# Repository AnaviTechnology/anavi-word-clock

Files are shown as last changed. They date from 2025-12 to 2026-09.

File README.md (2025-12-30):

# ANAVI Word Clock

Open source 8x8 NeoPixel word clock.

# Case

The case is designed using the free and open-source tool OpenSCAD and requires a custom stencil font.

## Installing the Stencil Font on Ubuntu

Follow the steps below to install the Arial stencil font on an Ubuntu Linux distribution:

*  Copy the font file:

```
sudo mkdir /usr/share/fonts/anavi
sudo cp Arial-BoldStencila.ttf /usr/share/fonts/anavi
sudo chmod -R --reference=/usr/share/fonts/opentype /usr/share/fonts/anavi
```

NOTE: Root privileges are required to install fonts system-wide.

* Update the font cache:

```
sudo fc-cache -fv
```

* Verify the installation:

```
fc-list | grep -i arial
```

The font should appear in the output list. The font name reported by fc-list must be used exactly in the OpenSCAD text() function.

* Launch OpenSCAD

Restart OpenSCAD if it was already running so it can detect the newly installed font.

# License

The project is released under the [Creative Commons Attribution-ShareAlike 4.0 International (CC BY-SA 4.0)](https://creativecommons.org/licenses/by-sa/4.0/).

Note: This is a human-readable summary of (and not a substitute for) the [license](https://creativecommons.org/licenses/by-sa/4.0/legalcode).

You are free to:

Share — copy and redistribute the material in any medium or format Adapt — remix, transform, and build upon the material for any purpose, even commercially. The licensor cannot revoke these freedoms as long as you follow the license terms. Under the following terms:

Attribution — You must give appropriate credit, provide a link to the license, and indicate if changes were made. You may do so in any reasonable manner, but not in any way that suggests the licensor endorses you or your use. ShareAlike — If you remix, transform, or build upon the material, you must distribute your contributions under the same license as the original. No additional restrictions — You may not apply legal terms or technological measures that legally restrict others from doing anything the license permits. Notices:

You do not have to comply with the license for elements of the material in the public domain or where your use is permitted by an applicable exception or limitation. No warranties are given. The license may not give you all of the permissions necessary for your intended use. For example, other rights such as publicity, privacy, or moral rights may limit how you use the material.

You will have to provide a link to the original creator of the project http://www.anavi.technology on any documentation or website.

Credit can be attributed through a link to the creator website: http://www.anavi.technology

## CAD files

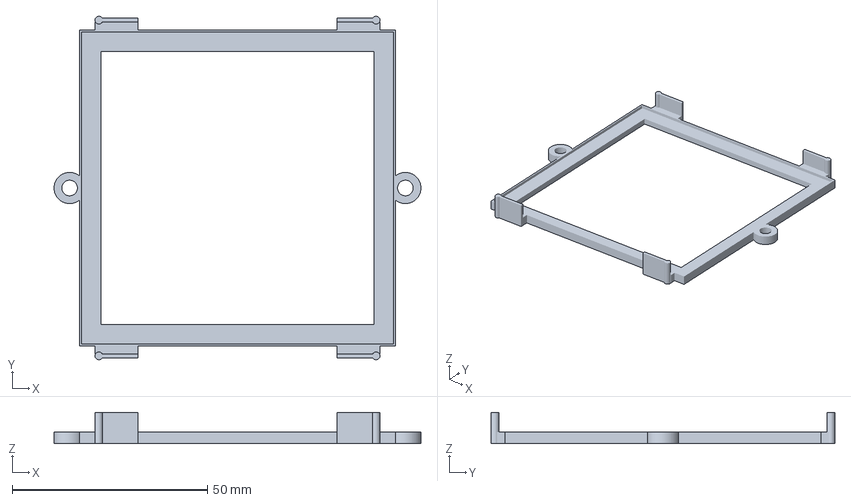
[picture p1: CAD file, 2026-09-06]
case/anavi-word-clock-panel.3mf
94.0 x 88.0 x 8.00 mm

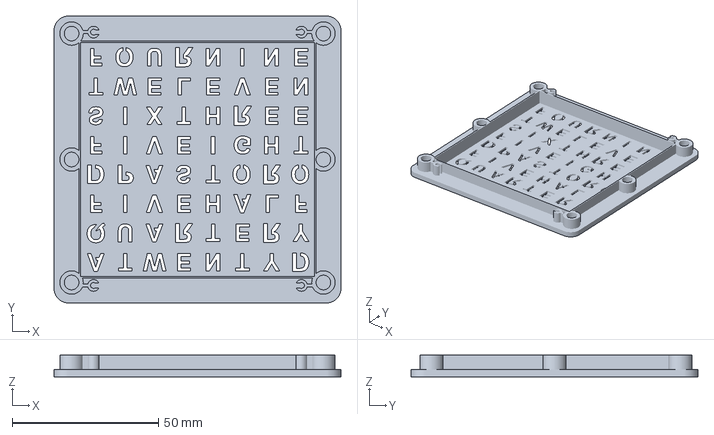
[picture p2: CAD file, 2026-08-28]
case/anavi-word-clock-top.3mf
98.0 x 98.0 x 7.50 mm

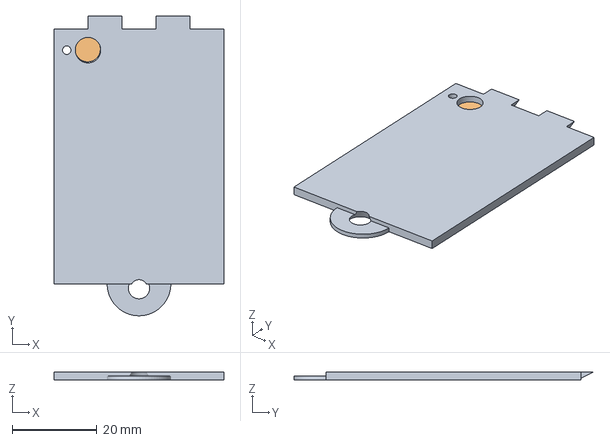
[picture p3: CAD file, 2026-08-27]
case/anavi-word-clock-cover.3mf
40.0 x 70.5 x 2.00 mm
anavi-word-clock-cover.stl
anavi-word-clock-cover-led.stl

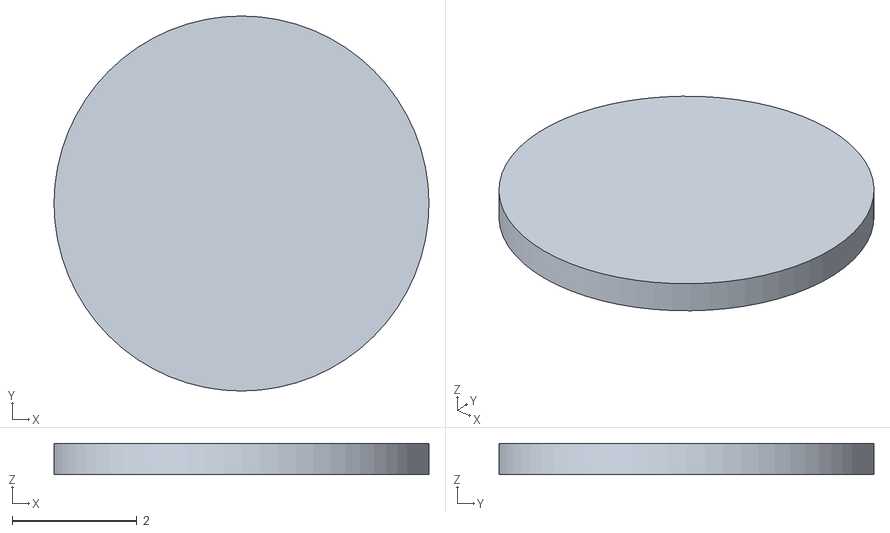
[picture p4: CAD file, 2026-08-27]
case/anavi-word-clock-cover-led.stl
6.00 x 6.00 x 0.5

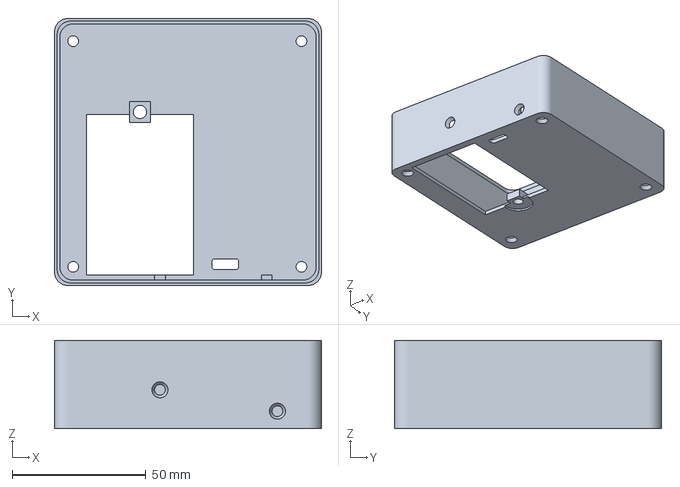
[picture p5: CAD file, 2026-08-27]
case/anavi-word-clock-back.3mf
100.0 x 100.0 x 33.0 mm

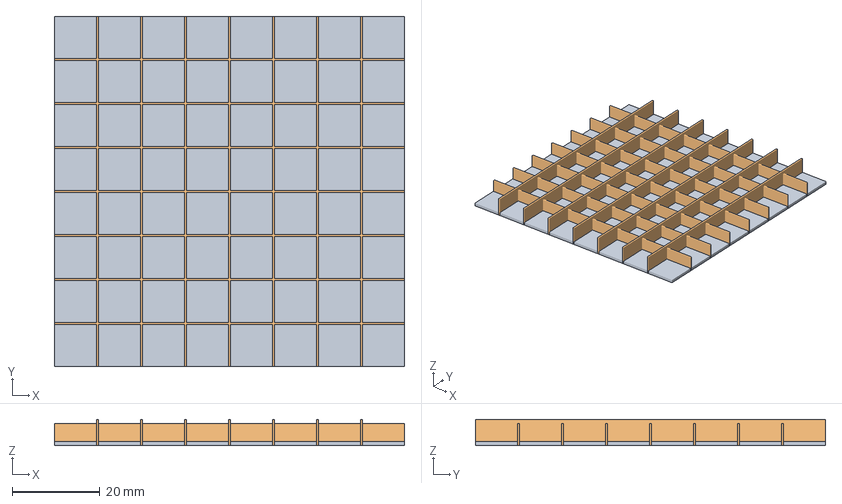
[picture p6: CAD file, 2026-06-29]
case/anavi-word-clock-grid-with-diffuser.3mf
80.0 x 80.0 x 6.00 mm
anavi-word-clock-diffuser.stl
anavi-word-clock-grid.stl

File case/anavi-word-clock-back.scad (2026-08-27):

// ========================
// Parameters
// ========================
// Corner radius
corner_r = 5;

// Wall thickness
wall_thickness = 2;
// smooth corners
$fn = 64;


// Case
case_width = 100;
case_lenght = 100;
case_height = 33;

// Outer cylinder
outer_r = 3;
outer_h = 4;

// Inner hole
hole_r = 3;
hole_h = 2;

// USB-C connector
usbc_l = 10;
usbc_h = 4;

// LED
led_r = 5;

// increase for smoother cone ($fn)
segments = 64;

// ========================
// Case Top Module
// ========================
module case_top() {

    // Translate so inner PCB pocket starts at (0,0)
    translate([corner_r, corner_r, 0]) {
        difference() {
            // Outer shell (walls included)
            linear_extrude(height = case_height)
                rounded_rect(case_width,
                             case_lenght,
                             corner_r);

            // Main hollow interior
            translate([wall_thickness, wall_thickness, wall_thickness])
                linear_extrude(height = case_height-3)
                    rounded_rect(case_width-2*wall_thickness, case_lenght-2*wall_thickness, corner_r);
            
            // Top hollow interior
            translate([wall_thickness/2, wall_thickness/2, case_height-3])
                linear_extrude(height = 3)
                    rounded_rect(case_width-wall_thickness, case_lenght-wall_thickness, corner_r);

            // Mounting hole 1 (top left)
            translate([2, case_lenght-4.5-hole_r*3, 0])
                // Cone
                cylinder(wall_thickness, hole_r, hole_h, center = false, $fn = segments);
            
            // Mounting hole 2 (top right)
            translate([case_width-4.5-hole_r*3+1, case_lenght-4.5-hole_r*3, 0])
                // Cone
                cylinder(wall_thickness, hole_r, hole_h, center = false, $fn = segments);

            // Mounting hole 2 (top right)
            translate([case_width-4.5-hole_r*3+1, hole_h, 0])
                // Cone
                cylinder(wall_thickness, hole_r, hole_h, center = false, $fn = segments);
            
            // Mounting hole 4 (bottom left)
            translate([2, 2, 0])
                // Cone
                cylinder(wall_thickness, hole_r, hole_h, center = false, $fn = segments);
        }
    }
    
    // Covel bottom holders
    translate([12+8-2, 2, wall_thickness])
        cube([12, 2, 2]);
    translate([12+24-2, 2, wall_thickness])
        cube([12, 2, 2]);

    // PCB stand
    middle = (case_width-usbc_l)/2+4;
    translate([middle-9.5-2, 2, wall_thickness])
        cube([4, 2, 10]);
    translate([middle+34.50-6, 2, wall_thickness])
        cube([4, 2, 23]);
}

// ========================
// Rounded rectangle module
// ========================
module rounded_rect(x, y, radius) {
    minkowski() {
        square([x - 2*radius, y - 2*radius], center = false);
        circle(r = radius, $fn = $fn);
    }
}

// ========================
// Mounting hole
// ========================
module mounting_hole() {
    difference() {
        // Outer cylinder
        cylinder(h = outer_h, r = outer_r, $fn = 64);
        
        // Inner hole
        translate([0, 0, outer_h-hole_h])  // hole starts at base
            cylinder(h = hole_h, r = hole_r, $fn = 64);
    }
}

module usbc() {
    linear_extrude(height = wall_thickness)
        rounded_rect(usbc_l,usbc_h,1);
}

module ramp_screw() {
    rotate([90, 0, 270])
    linear_extrude(height = 8)
        polygon([
            [0, 0],
            [4, 0],
            [4, 1]
        ]);
}

module ramp() {
    rotate([270, 0, 90])
    linear_extrude(height = 8)
        polygon([
            [0, 0],
            [3, 0],
            [3, 3]
        ]);
}

// ========================
// Top case
// ========================

difference() {
    union() {
        difference() {
            // Main part of the case
            case_top();
            // USB-C connector
            translate([(case_width-usbc_l)/2+15, 7, 0])
               usbc();
            // PCB mounting holes
            middle = (case_width-usbc_l)/2+4;
            translate([middle-9.5, 2, wall_thickness+2.5+2+8])
                rotate([90, 0, 0])
                    cylinder(h = 2, r1 = 2, r2 = 3, center = false);

            translate([middle+34.5, 2, wall_thickness+2.5+2])
                rotate([90, 0, 0])
                    cylinder(h = 2, r1 = 2, r2 = 3, center = false);
            
            // Cover for the RTC module
            translate([12, 4, 0])
                cube([40, 60, 2]);
            translate([12+40/2,65,0])
                cylinder(h = 1, d = 15, $fn = segments);
            
            translate([12+16, 1, 3])
                ramp();
            translate([12+32, 1, 3])
                ramp();
        }
        
        // Holder for the cover's nut
        translate([8+40/2,61,1])
            cube([8, 8, 4]);
    }
    
    // Cover's mounting hole
    translate([12+40/2,65,1])
        cylinder(4, 2.5, 2.5, center = false, $fn = segments);

}

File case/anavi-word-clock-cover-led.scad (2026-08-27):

// increase for smoother cone ($fn)
segments = 64;

cylinder(0.5, 3, 3, center = false, $fn = segments);

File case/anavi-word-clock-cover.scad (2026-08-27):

// increase for smoother cone ($fn)
segments = 64;

// Inner hole
hole_r = 3;
hole_h = 2;

module ramp() {
    rotate([90, 0, 90])
    linear_extrude(height = 8)
        polygon([
            [0, 0],
            [3, 0],
            [3, 1.5]
        ]);
}

difference() {
    union() {
        cube([40, 60, 2]);
        translate([40/2,60,1])
            cylinder(h = 1, d = 15, $fn = segments);
        
        translate([8,-3,0])
            ramp();
        
        translate([24,-3,0])
            ramp();
    }

    // Opening for the screw
    translate([40/2,61,0])
        cylinder(2, hole_h, hole_r, center = false, $fn = segments);

    // Opening for the reset button
    translate([3,5,0])
        cylinder(2, 1, 1, center = false, $fn = segments);

    // LED
    translate([8,5,0])
        cylinder(2, 3, 3, center = false, $fn = segments);
}

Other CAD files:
case/anavi-word-clock-grid.scad
case/anavi-word-clock-back.stl
case/anavi-word-clock-cover.stl
case/anavi-word-clock-panel.scad
case/anavi-word-clock-panel.stl
case/anavi-word-clock-top.scad

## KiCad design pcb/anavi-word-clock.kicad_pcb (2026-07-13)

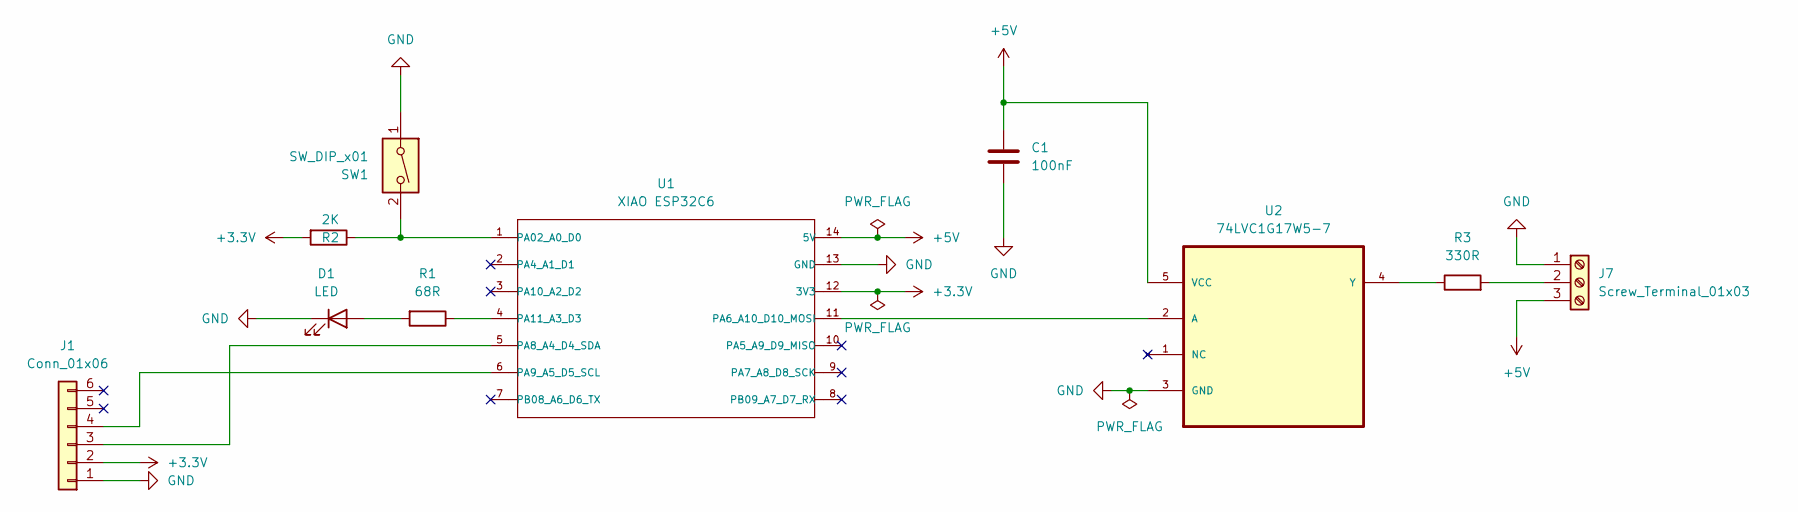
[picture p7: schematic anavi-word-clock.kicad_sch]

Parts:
C1: 100nF
D1: LED; LED_1206_3216Metric
J1: Conn_01x06; PinSocket_1x06_P2.54mm_Horizontal
J7: Screw_Terminal_01x03; TerminalBlock_Phoenix_MKDS-1,5-3_1x03_P5.00mm_Horizontal
R1: 68R; R_0603_1608Metric_Pad0.98x0.95mm_HandSolder
R2: 2K; R_0603_1608Metric_Pad0.98x0.95mm_HandSolder
R3: 330R; R_0603_1608Metric_Pad0.98x0.95mm_HandSolder
SW1: SW_DIP_x01; SW_TL1105SF160Q_EWI
U1: XIAO ESP32C6; XIAO-ESP32-C6-SMD
U2: 74LVC1G17W5-7; SOT95P280X145-5N; MPN 74LVC1G17W5-7

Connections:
+3.3V: J1.2, R2.2, U1.12 (3V3)
+5V: C1.1, J7.3, U1.14 (5V), U2.5 (VCC)
GND: C1.2, D1.1 (K), J1.1, J7.1, SW1.1, U1.13 (GND), U2.3 (GND)
unnamed: D1.2 (A), R1.2
unnamed: J1.3, U1.5 (PA8_A4_D4_SDA)
unnamed: J1.4, U1.6 (PA9_A5_D5_SCL)
unnamed: J7.2, R3.2
unnamed: R2.1, SW1.2, U1.1 (PA02_A0_D0)
unnamed: U1.11 (PA6_A10_D10_MOSI), U2.2 (A)
unnamed: R1.1, U1.4 (PA11_A3_D3)
unnamed: R3.1, U2.4 (Y)

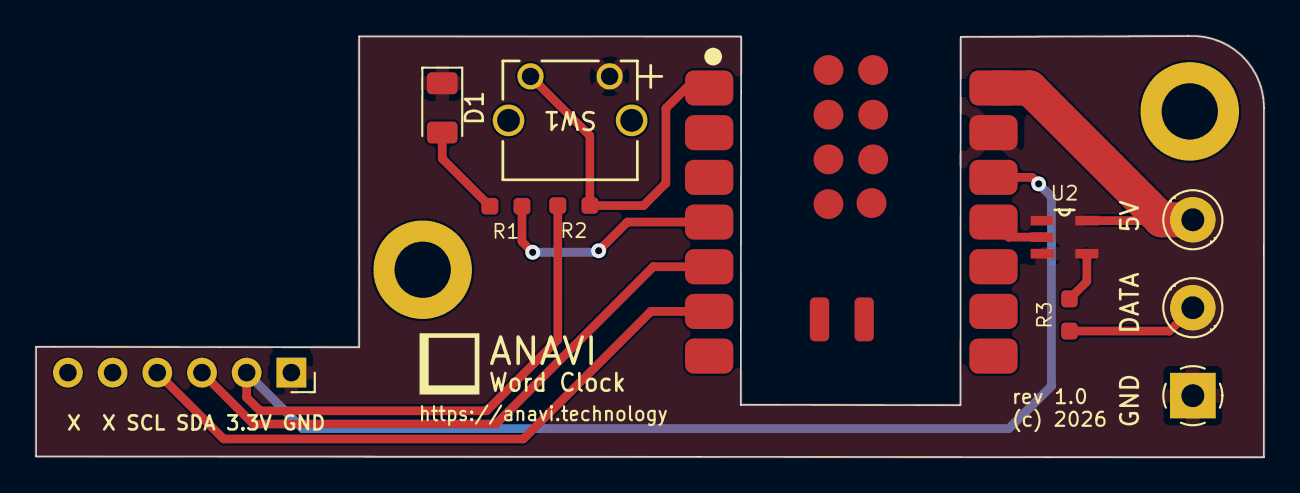
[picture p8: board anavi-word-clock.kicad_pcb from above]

Board: 2 copper layers, 69.8 x 23.9 mm, 9 parts (0 on the bottom side), 11 nets.

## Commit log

2025-12-29 case: Add anavi-word-clock-top.scad
    OpenSCAD design file for the top part with letters.
    [anavi-word-clock-top.scad]
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2025-12-30 case: Use stencil font
    Modify the top of the case to use the appropriate stencil font.
    [anavi-word-clock-top.scad]
2025-12-30 case/anavi-word-clock-top.scad: Add grid
    Add 8x8 grid with a cell for each NeoPixel.
    [anavi-word-clock-top.scad]
2025-12-30 case/anavi-word-clock-top.scad: Reduce size
    Reduce size from 100mm to 98mm. The top part is 2 mm shorter than
    the bottom, aka 1 mm on each side. So the whole case will be 10cm.
    [anavi-word-clock-top.scad]
2025-12-30 case: Add anavi-word-clock-back.scad
    Add OpenSCAD design for the back cover of the clock.
    [anavi-word-clock-back.scad]
2025-12-30 case/anavi-word-clock-top.scad: Grid height
    Reduce grid height to 4mm and adjust the position.
    [anavi-word-clock-top.scad]
2025-12-31 case/anavi-word-clock-diffuser.scad: Add
    Add a small plate that should act as a light diffuser.
    [anavi-word-clock-diffuser.scad]
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2026-01-01 case/anavi-word-clock-grid.scad: Add
    Add a 3D model of a grid between the NeoPixel panel (in its cover)
    and the diffuser.
    [anavi-word-clock-grid.scad]
2026-01-01 case/anavi-word-clock-top.scad: Mounting holes
    Add mounting holes in the middle to hold the NeoPixel panel.
    [anavi-word-clock-top.scad]
2026-01-03 case/anavi-word-clock-panel.scad: Add hooks
    Add four hooks to firmly attach the panel with NeoPixels to the
    front part of the clock.
    [anavi-word-clock-panel.scad]
2026-01-03 case/anavi-word-clock-top.scad: Add hooks
    Increase grid height to 5mm and add four hooks to firmly attach
    the NeoPixel panel cover to the front of the word clock.
    [anavi-word-clock-top.scad]
2026-01-03 case/anavi-word-clock-grid.scad: Adjust size
    Increase the grid height to 5mm, adjust the total size to 81mm.
    [anavi-word-clock-grid.scad]
2026-01-04 anavi-word-clock-back.scad: PCB mounting holes
    Add two PCB mounting holes for ANAVI Miracle Emitter.
    [anavi-word-clock-back.scad]
2026-01-04 case/anavi-word-clock-panel.scad: Hook positions
    Adjust the hook positions so they align precisely with the top
    plate.
    [anavi-word-clock-panel.scad]
2026-01-05 case/anavi-word-clock-back.scad: Adjust position
    Adjust the vertical position of the mounting holes for the printed
    circuit board, a.k.a for ANAVI Miracle Emitter.
    [anavi-word-clock-back.scad]
2026-01-05 case/anavi-word-clock-back.stl: Add
    Add STL for the back part of ANAVI Word Clock.
    [anavi-word-clock-back.stl]
2026-01-05 case/anavi-word-clock-back: Increase to 55mm
    Increase from 50mm to 55mm because of the M3 50mm standard screws.
    [anavi-word-clock-back.scad, anavi-word-clock-back.stl]
2026-01-06 case/anavi-word-clock-back.scad: Reduce to 45mm
    Following some optimizations of the from we can reduce the depth
    to 45mm for ANAVI Miracle Emitter.
    [anavi-word-clock-back.scad]
2026-01-06 case/anavi-word-clock-grid.scad: Diffuser
    Generate either grid or a diffuser with the same code.
    [anavi-word-clock-diffuser.scad, anavi-word-clock-grid.scad]
2026-01-06 case/anavi-word-clock-top.scad: No grid
    Don't draw grid because it will be a separate part.
    [anavi-word-clock-top.scad]
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2026-01-11 pcb: ANAVI Word Clock PCB
    Initial version of a printed circuit board based on ANAVI Miracle
    Emitter with various modifications to make it specific for ANAVI
    Word Clock.
    [anavi-word-clock.kicad_pcb, anavi-word-clock.kicad_sch]
2026-06-27 anavi-word-clock-top.scad: Increase hole depth
    Increase the inner hole depth for M3 brass threaded inserts from
    2 mm to 4 mm.
    [anavi-word-clock-top.scad]
2026-06-27 anavi-word-clock-grid-with-diffuser.3mf: Add file
    Add .3mf file that combines black grid with white diffuser.
    [anavi-word-clock-grid-with-diffuser.3mf]
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2026-06-28 anavi-word-clock-grid.scad: Increase cell height
    Increase the height of each cell in the grid from 0.5 to 1.
    [anavi-word-clock-grid.scad]
2026-06-28 anavi-word-clock-panel.stl: Add file
    Add STL for the internal part that holds the NeoPixel LED panel.
    [anavi-word-clock-panel.stl]
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2026-07-11 pcb: Change the PCB design
    Update the schematics and change the PCB design to support I2C RTC
    module with 1x6 female connector.
    [anavi-word-clock.kicad_pcb, anavi-word-clock.kicad_sch]
2026-07-12 pcb: Use XIAO ESP32C6
    Switch the footprint from XIAO ESP32C3 to ESP32C6 because of the
    on-board antenna with up to 80m BLE/Wi-Fi range which makes the
    assembly of the clock easier.
    [anavi-word-clock.kicad_pcb, anavi-word-clock.kicad_sch]
2026-07-12 pcb: anavi-word-clock.kicad_pcb: Fix errors
    Fix DRC errors and warnings.
    [anavi-word-clock.kicad_pcb]
2026-07-13 pcb: anavi-word-clock: Fix warnings
    Edit footprints and fix warnings in the PCBview.
    [anavi-word-clock.kicad_pcb]
2026-07-30 case/anavi-word-clock-back: Adjust dimensions
    Adjust dimensions and mounting holes for the new ANAVI Word Clock
    printed circuit board with XIAO ESP32C6.
    [anavi-word-clock-back.scad, anavi-word-clock-back.stl]
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2026-08-26 case/anavi-word-clock-cover.*: Add files
    Add OpenSCAD and STL files for the cover. It is required for easy
    access to the RTC module without disassembling the whole clock.
    [anavi-word-clock-cover.scad, anavi-word-clock-cover.stl]
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

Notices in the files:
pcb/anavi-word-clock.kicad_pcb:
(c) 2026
